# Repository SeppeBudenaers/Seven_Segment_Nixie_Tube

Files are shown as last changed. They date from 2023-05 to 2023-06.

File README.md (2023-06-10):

# Seven Segment Nixie Tube
 This repository contains the code and design files for a LED filament seven segment display, designed to resemble a nixie tube. The display can be configured in either common anode or WS2811 mode, providing a modern twist on the classic nixie tube aesthetic. It provides a warm glow to resemble a nixie tube while taking advantage of LED technology. Explore the provided files to build your own LED filament seven segment display and infuse your projects with a touch of vintage charm.
## How to use it 
To configure the LED filament seven segment display to common anode mode, solder the first and second pads of every solder bridge together.

To configure the LED filament seven segment display to WS2811 mode, solder the second and third pads of every solder bridge together.
## Bill of Material
### common anode mode

| Item | Quantity | Link |
|---|---|---|
| Glas tube 30x60mm | x1 | [AliExpress Link](https://nl.aliexpress.com/item/32813289039.html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) |
| Red LED filament | x7 | [AliExpress Link](https://nl.aliexpress.com/item/1005003834518235.html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) |
| 47 ohm resistors | x7 | [LCSC Link](https://www.lcsc.com/product-detail/_UNI-ROYAL-Uniroyal-Elec-_C25315.html) |
| 8 2,54mm pinheader reverse bending 90° | x1 | [AliExpress Link](https://nl.aliexpress.com/item/4000660389713.html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) |

### WS2811 mode

| Item | Quantity | Link |
|---|---|---|
| Glas tube 30x60mm | x1 | [AliExpress Link](https://nl.aliexpress.com/item/32813289039.html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) |
| Red LED filament | x7 | [AliExpress Link](https://nl.aliexpress.com/item/1005003834518235.html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) |
| 47 ohm resistor | x7 | [LCSC Link](https://www.lcsc.com/product-detail/_UNI-ROYAL-Uniroyal-Elec-_C25315.html) |
| 100 ohm resistor | x3 | [LCSC Link](https://www.lcsc.com/product-detail/_UNI-ROYAL-Uniroyal-Elec-_C17408.html) |
| WS2811 | x3 | [LCSC Link](https://www.lcsc.com/product-detail/LED-Drivers_Worldsemi-WS2811_C114581.html) |
| 8 2,54mm pinheader reverse bending 90° | x1 | [AliExpress Link](https://nl.aliexpress.com/item/4000660389713.html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) |

## todo
- [ ] Add media.
- [ ] Write a library for arduino to use my segments in WS2811 mode.

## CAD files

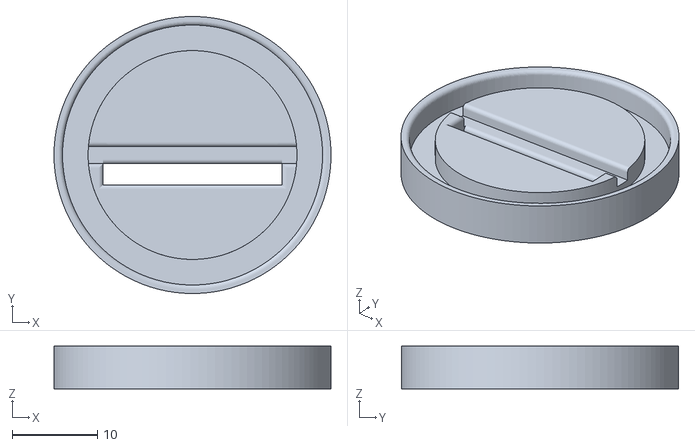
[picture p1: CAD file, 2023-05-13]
Fusion_360/STL_Files/Seven_segment_Cap.stl
32.5 x 32.5 x 5.00

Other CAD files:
Fusion_360/Seven Segment Nixie Tube v12.f3d

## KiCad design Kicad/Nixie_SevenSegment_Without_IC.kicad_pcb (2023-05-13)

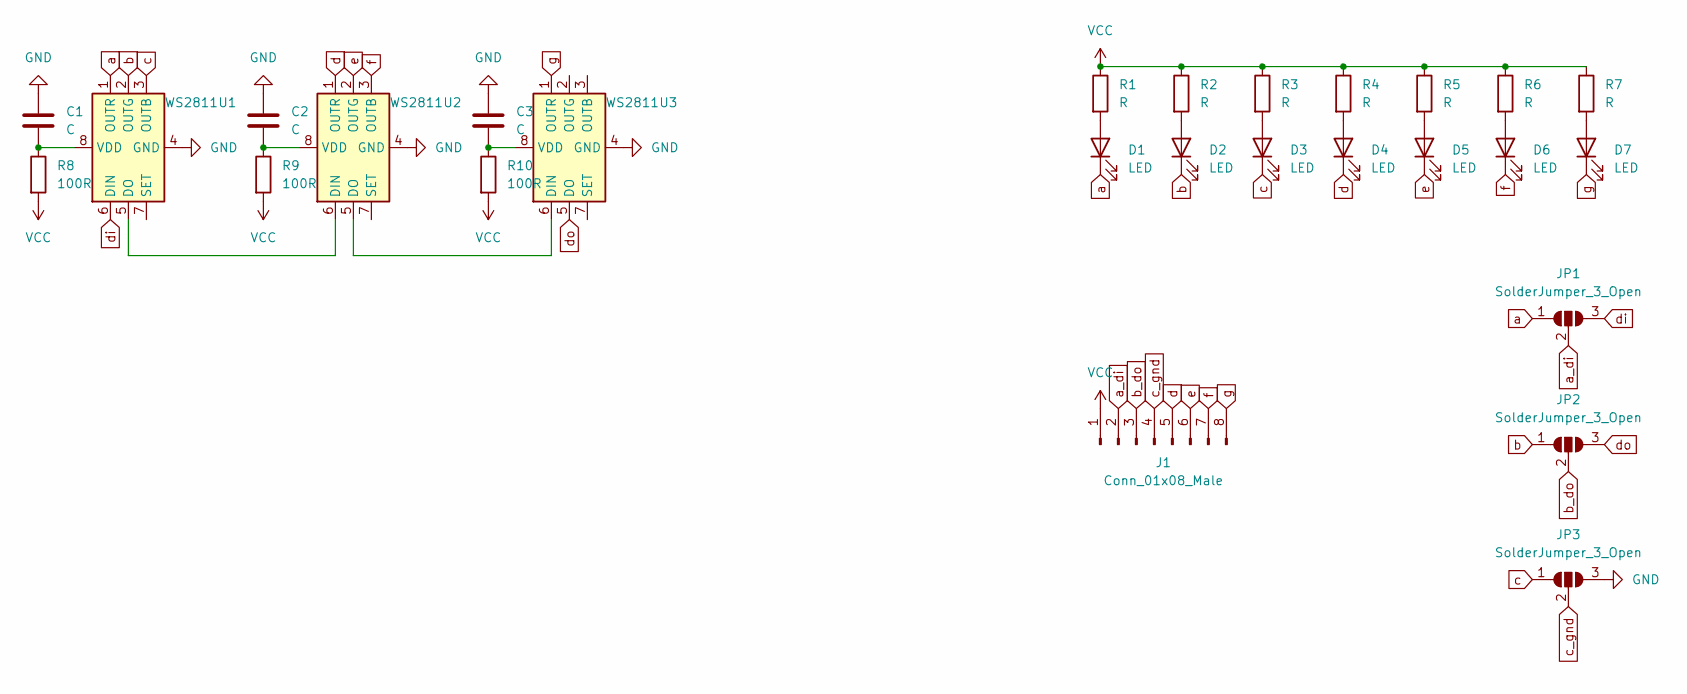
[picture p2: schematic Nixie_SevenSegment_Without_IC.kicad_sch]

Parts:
C1, C2, C3: C; C_0805_2012Metric_Pad1.18x1.45mm_HandSolder
D1, D2, D3, D4, D5, D6, D7: LED; LEDFilament_12mm
J1: Conn_01x08_Male; PinSocket_1x08_P2.54mm_Vertical
JP1, JP2, JP3: SolderJumper_3_Open; SolderJumper-3_P1.3mm_Open_Pad1.0x1.5mm
R1, R2, R3, R4, R5, R6, R7: R; R_0805_2012Metric_Pad1.20x1.40mm_HandSolder
R8, R9, R10: 100R; R_0805_2012Metric_Pad1.20x1.40mm_HandSolder
U1, U2, U3: WS2811; SOP-8_3.9x4.9mm_P1.27mm

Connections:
GND: C1.2, C2.2, C3.2, JP3.3 (B), U1.4 (GND), U2.4 (GND), U3.4 (GND)
unnamed: C1.1, R8.1, U1.8 (VDD)
unnamed: C2.1, R9.1, U2.8 (VDD)
unnamed: C3.1, R10.1, U3.8 (VDD)
unnamed: D1.2 (A), R1.2
unnamed: D2.2 (A), R2.2
unnamed: D3.2 (A), R3.2
unnamed: D4.2 (A), R4.2
unnamed: D5.2 (A), R5.2
unnamed: D6.2 (A), R6.2
unnamed: D7.2 (A), R7.2
unnamed: U1.5 (DO), U2.6 (DIN)
unnamed: U2.5 (DO), U3.6 (DIN)
VCC: J1.1, R1.1, R2.1, R3.1, R4.1, R5.1, R6.1, R7.1, R8.2, R9.2, R10.2
a: D1.1 (K), JP1.1 (A), U1.1 (OUTR)
a_di: J1.2, JP1.2 (C)
b: D2.1 (K), JP2.1 (A), U1.2 (OUTG)
b_do: J1.3, JP2.2 (C)
c: D3.1 (K), JP3.1 (A), U1.3 (OUTB)
c_gnd: J1.4, JP3.2 (C)
d: D4.1 (K), J1.5, U2.1 (OUTR)
di: JP1.3 (B), U1.6 (DIN)
do: JP2.3 (B), U3.5 (DO)
e: D5.1 (K), J1.6, U2.2 (OUTG)
f: D6.1 (K), J1.7, U2.3 (OUTB)
g: D7.1 (K), J1.8, U3.1 (OUTR)

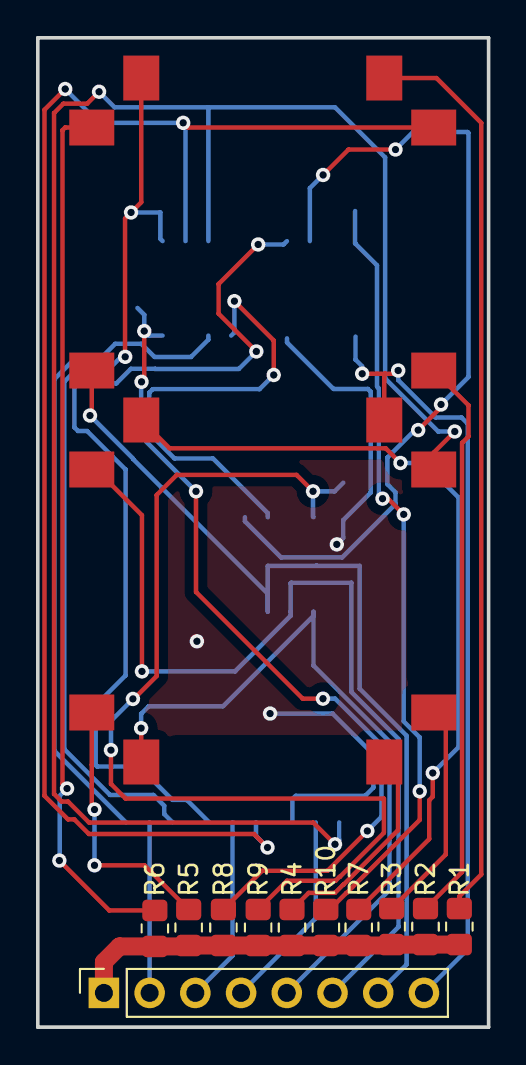
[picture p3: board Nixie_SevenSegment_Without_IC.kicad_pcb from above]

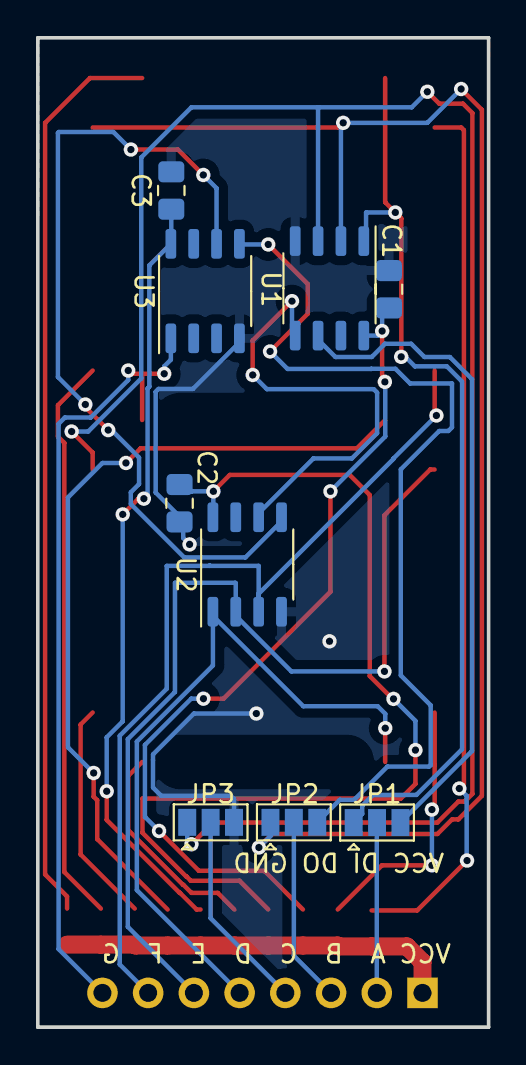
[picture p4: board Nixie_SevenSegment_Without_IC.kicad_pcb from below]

Board: 2 copper layers, 25.0 x 55.0 mm, 27 parts (9 on the bottom side), 26 nets.

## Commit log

2023-05-13 structure changes
    [Nixie_SevenSegment_Without_IC.kicad_pcb, Nixie_SevenSegment_Without_IC.kicad_sch]
2023-05-13 Update README.md
    added how to use and BOM
2023-05-13 added 3D cap
    [Seven_segment_Cap.stl]
2023-05-13 added resistor values
    [Nixie_SevenSegment_Without_IC.kicad_sch]
2023-06-10 updated readability
    changed readme
    Made folder names more clear
    Added fusion 360 file for the segment
    [Nixie_SevenSegment_Without_IC.kicad_pcb, Nixie_SevenSegment_Without_IC.kicad_sch, Seven Segment Nixie Tube v12.f3d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]
